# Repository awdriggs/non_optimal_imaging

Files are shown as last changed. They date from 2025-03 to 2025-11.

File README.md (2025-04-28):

This project explores how “non-optimal” digital cameras can be used to critically analyze photography. Each camera is missing one or more of the key affordances of a modern camera. By reintroducing limitations we can begin to understand our collective and individual relationships with photography at a moment when photography itself is being rapidly reshaped by machine learning.

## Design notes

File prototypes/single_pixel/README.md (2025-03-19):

# Single Pixel Camera
A "camera" that captures a single color value.

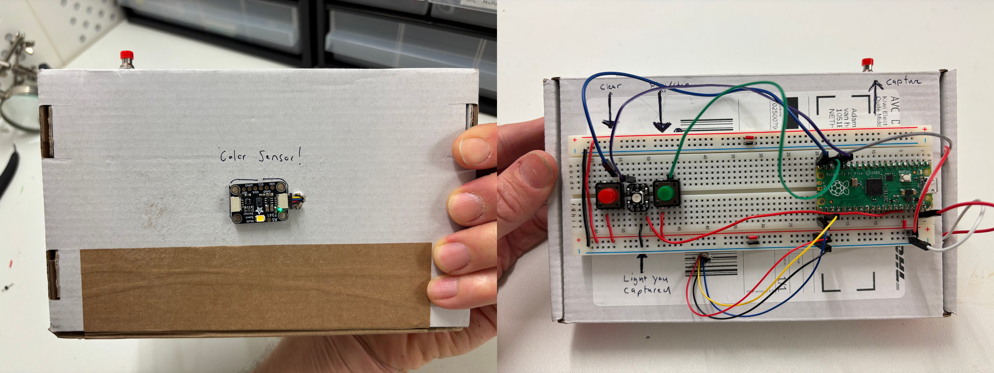
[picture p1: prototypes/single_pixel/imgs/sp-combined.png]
one pixel camera


The device uses a multispectral light sensor to capture visual light when a button is pressed. The multispectral data is converted to an RGB value and displayed on a single RGB led.
Buttons are used to review the captured colors and to clear the output.

Currently, there is no way to capture the colors from the device and they are deleted whenever the device is turned off.

## Components
- [Raspberry Pi Pico V1](https://www.raspberrypi.com/products/raspberry-pi-pico/)
- [Adafruit AS 7341 Multispectral Sensor](https://www.adafruit.com/product/4698)
- A Single [Neopixel](https://www.adafruit.com/product/1904)
- Three push buttons
- 3.3v LiPo battery
- [Adafruit Micro-Lipo Charger](https://www.adafruit.com/product/1904)

## Circuit
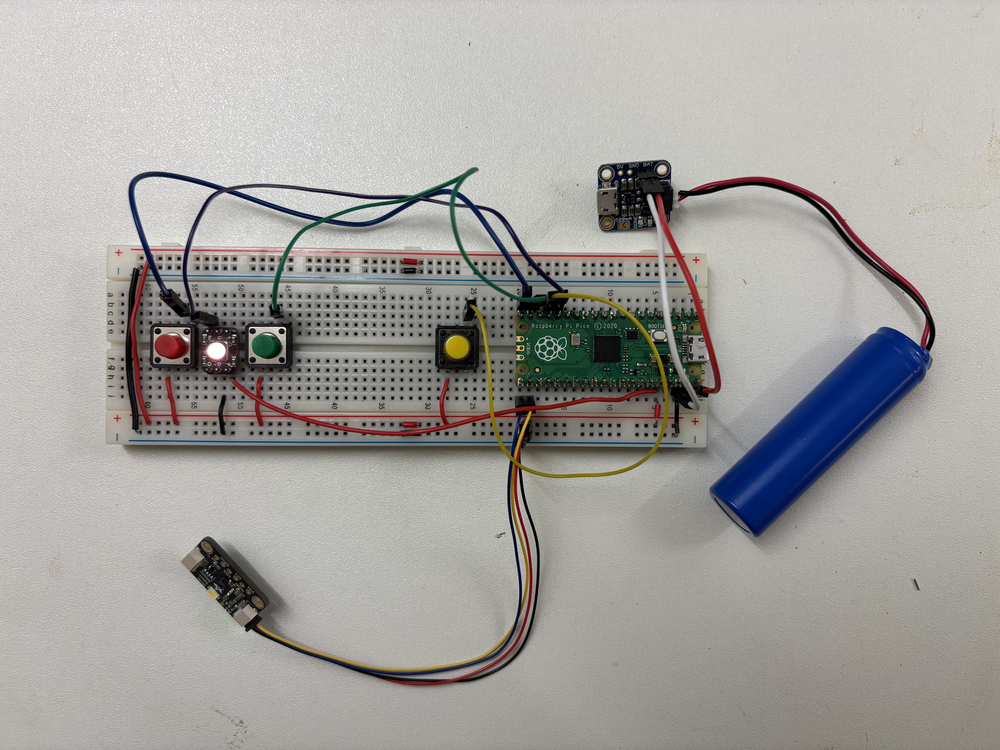
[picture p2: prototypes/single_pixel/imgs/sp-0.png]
breadboarded circuit


- Neopixel data to GP12
- Capture button to GP13
- Play button to GP14
- Clear button to GP15
- Sensor SCL to GP17
- Sensor SDA to GP16

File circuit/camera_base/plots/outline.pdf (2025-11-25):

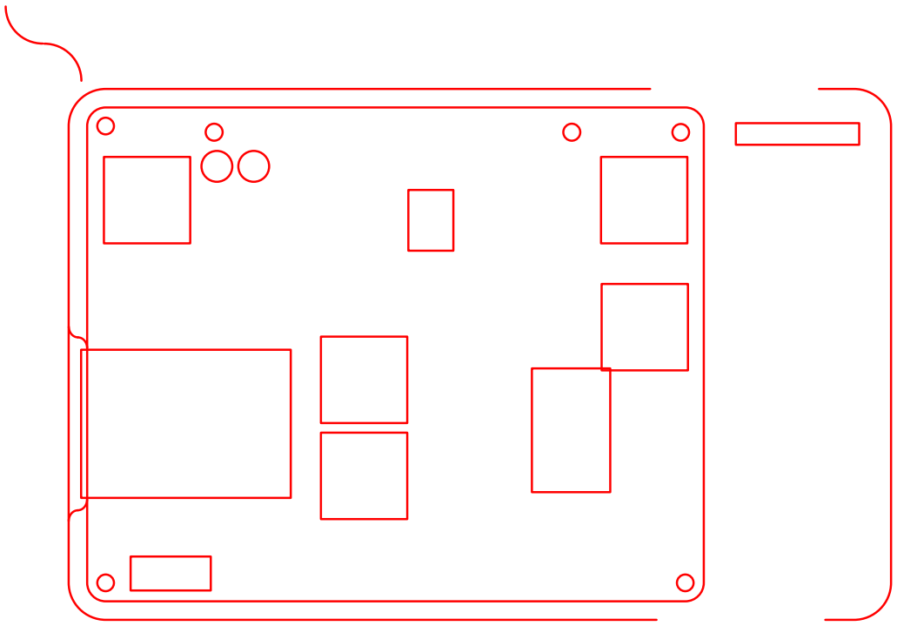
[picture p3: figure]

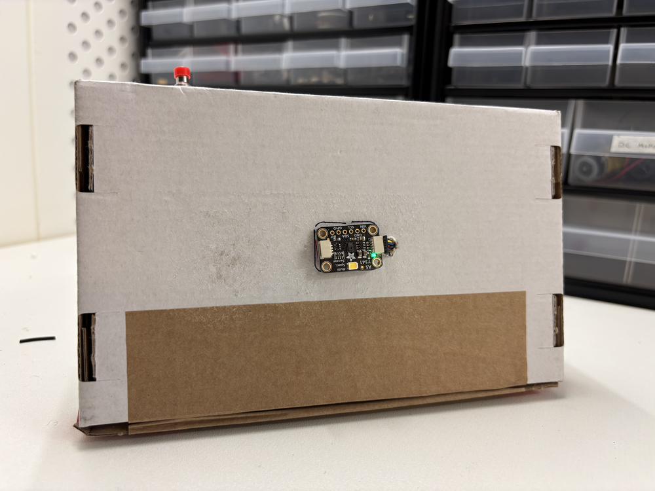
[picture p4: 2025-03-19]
prototypes/single_pixel/imgs/sp-8.png

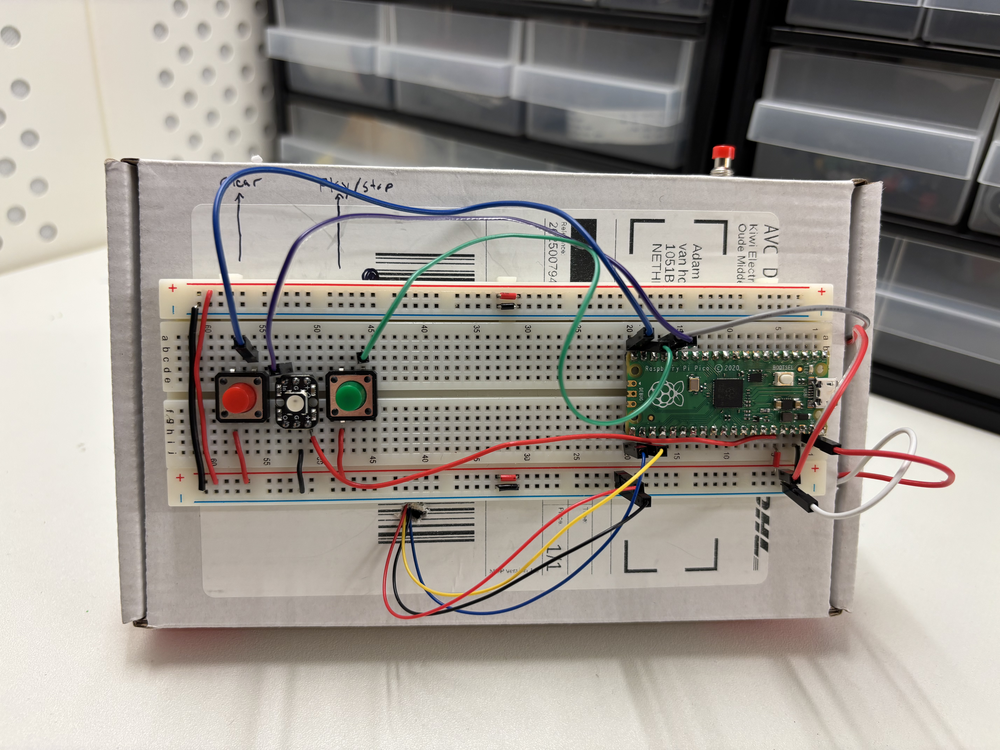
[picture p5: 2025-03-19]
prototypes/single_pixel/imgs/sp-9.png

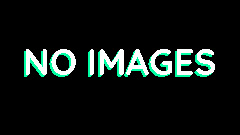
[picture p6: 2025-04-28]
camera/frontend/screens/no-images.jpg

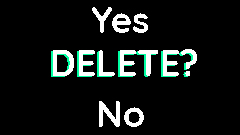
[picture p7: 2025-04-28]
camera/frontend/screens/delete.jpg

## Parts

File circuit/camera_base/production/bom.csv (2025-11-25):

Designator | Footprint | Quantity | Value | LCSC Part #
D1 | LED_D3.0mm | 1 | GPIO_19
D2 | LED_D3.0mm | 1 | LED
J1 | MODULE_RASPBERRY_PI_ZERO_2_W | 1 | Raspberry_Pi_4
J2 | PinHeader_2x03_P2.54mm_Vertical | 1 | Conn_02x03_Odd_Even
LIPO RIDER | SEED Studio LIPO Rider Plus | 1 | ~
R1, R2 | R_Axial_DIN0204_L3.6mm_D1.6mm_P5.08mm_Vertical | 2 | R
RV1 | Potentiometer_Alps_RK163_Single_Horizontal | 1 | R_Potentiometer_US
S4 | 5D_Button | 1 | ~
SCREEN | TFT 1.14 | 1 | ~
SW1, SW2, SW3, SW5 | PUSH_BUTTON_12mm | 4 | SW_Push_Dual
U1 | switch | 1 | ~

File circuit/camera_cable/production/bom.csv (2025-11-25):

Designator | Footprint | Quantity | Value | LCSC Part #
J1 | FPC_15pin_1mm_Vertical | 1 | ~
J2 | FPC_22pin_0.5mm_Vertical | 1 | ~

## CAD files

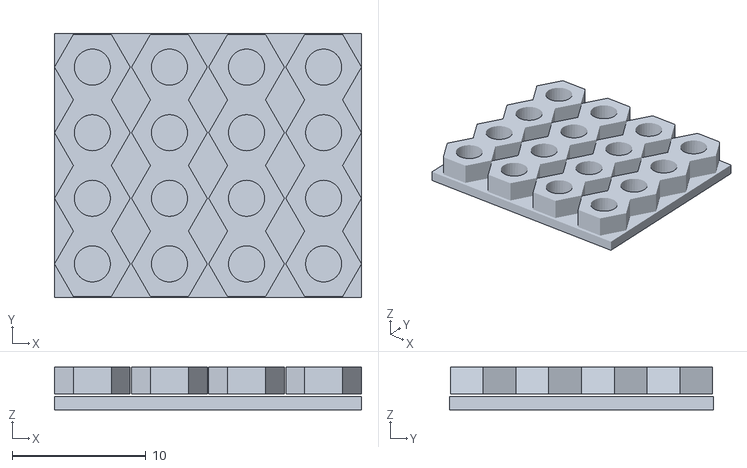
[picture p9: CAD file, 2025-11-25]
enclosure/spacer.stl
22.9 x 19.7 x 3.20

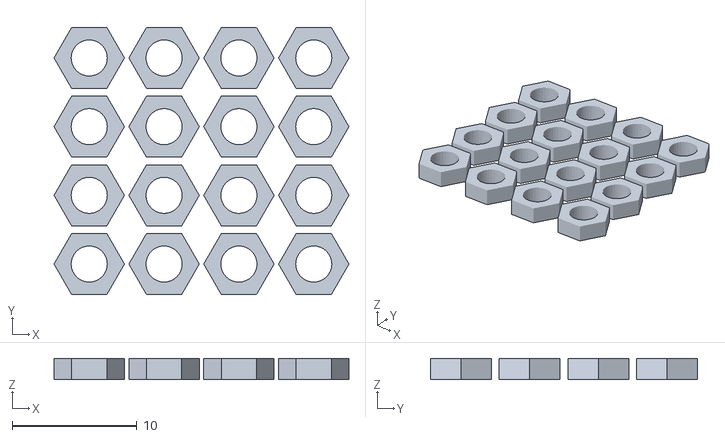
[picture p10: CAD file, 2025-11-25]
enclosure/spacers_no_base.stl
23.7 x 21.4 x 1.70

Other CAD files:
enclosure/no_enclosure_cut_ready.3dm

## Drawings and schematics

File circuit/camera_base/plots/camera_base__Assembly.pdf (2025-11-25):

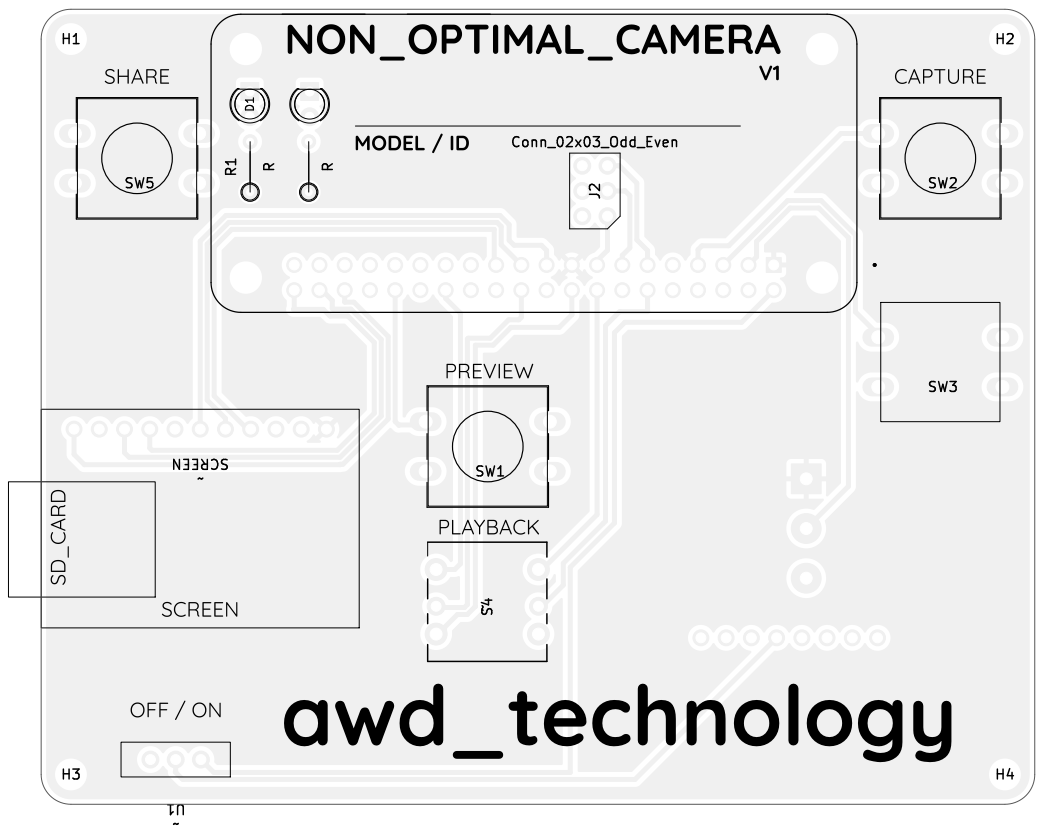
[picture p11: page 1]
D Date: KiCad; E.D.A. 9.0.1 Size: A4; Rev:; Id: /1 Title: File: camera_base.kicad_pcb Sheet: Black; And; White; TOP; Board2Pdf:; Black; TOP -; Page; ~S4 SW5 H1 H2 D1 H4 SW3 SW2 ~U1 SW1 Conn_02x03_Odd_Even J2 H3

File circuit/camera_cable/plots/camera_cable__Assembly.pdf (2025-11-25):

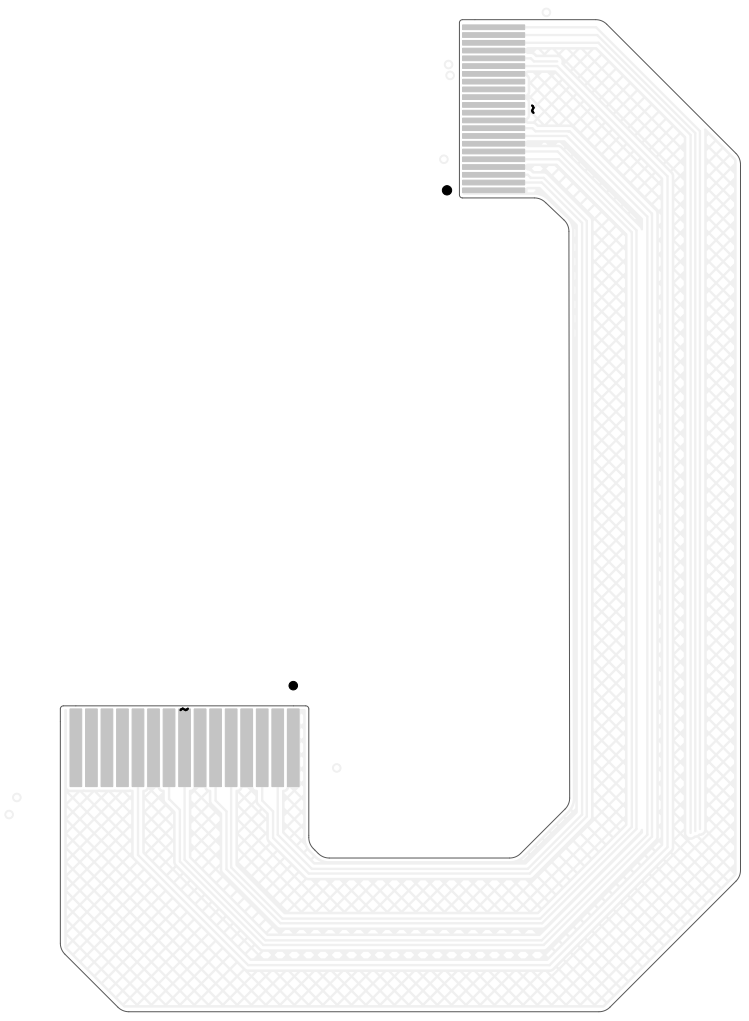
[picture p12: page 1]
D Date: KiCad; E.D.A. 9.0.1 Size: A4; Rev:; Id: /1 Title: File: camera_cable.kicad_pcb Sheet: Black; And; White; TOP; Board2Pdf:; Black; TOP -; Page

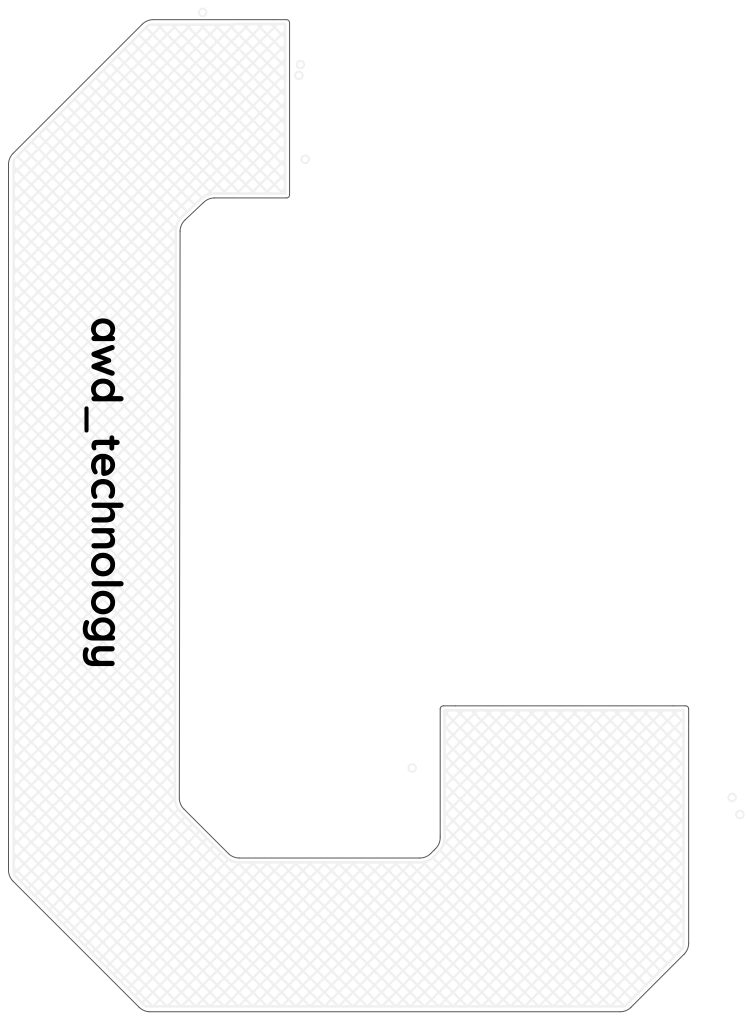
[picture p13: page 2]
D Date: KiCad; E.D.A. 9.0.1 Size: A4; Rev:; Id: /1 Title: File: camera_cable.kicad_pcb Sheet: Black; And; White; BOT Board2Pdf:; Black; BOT -; Page 2/2

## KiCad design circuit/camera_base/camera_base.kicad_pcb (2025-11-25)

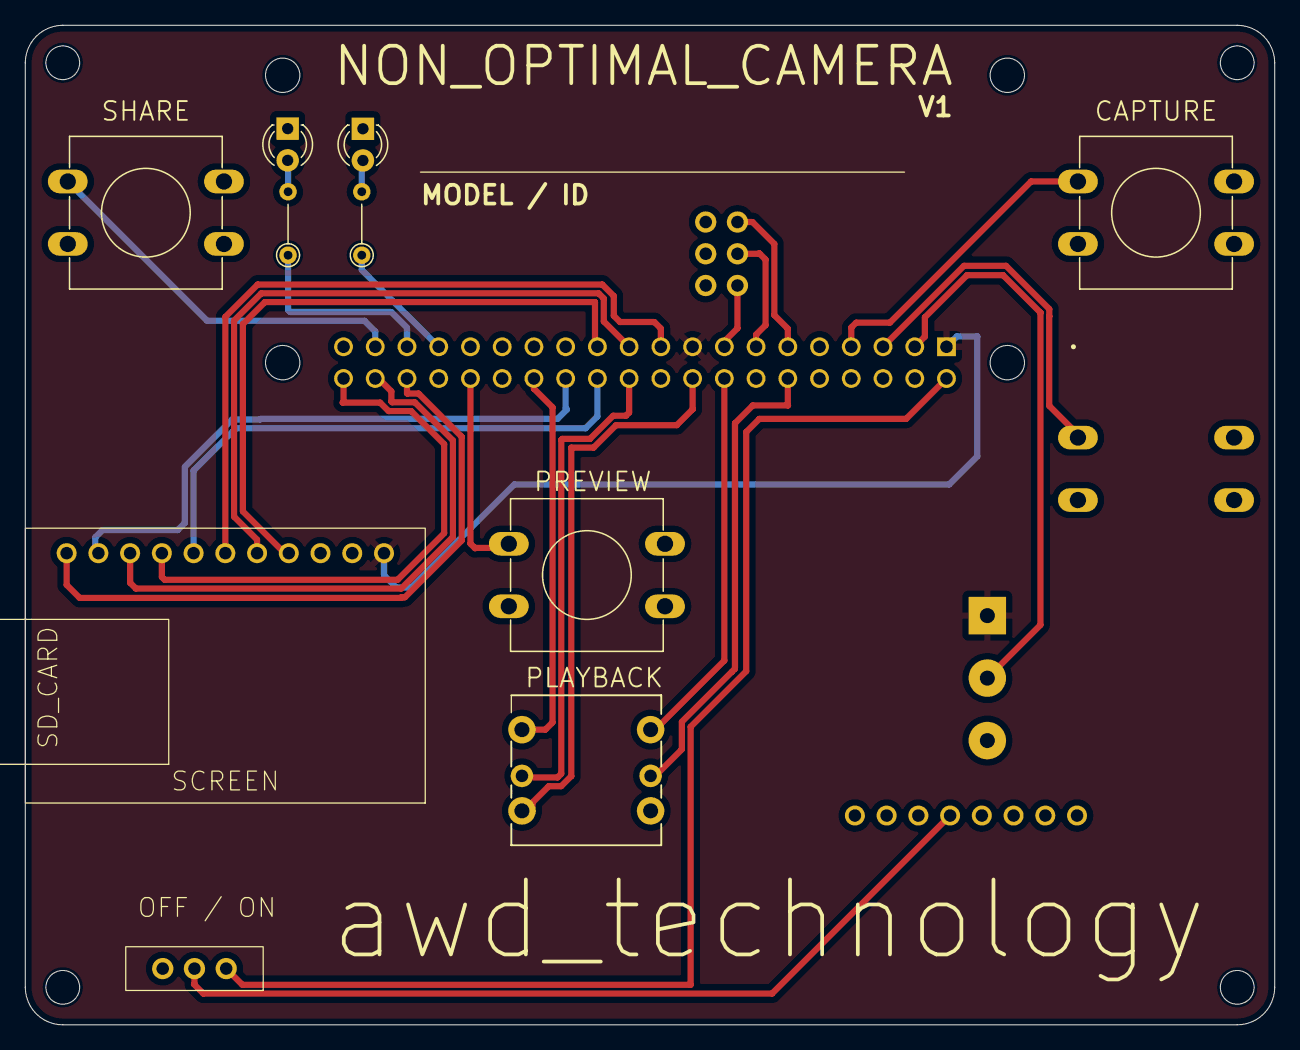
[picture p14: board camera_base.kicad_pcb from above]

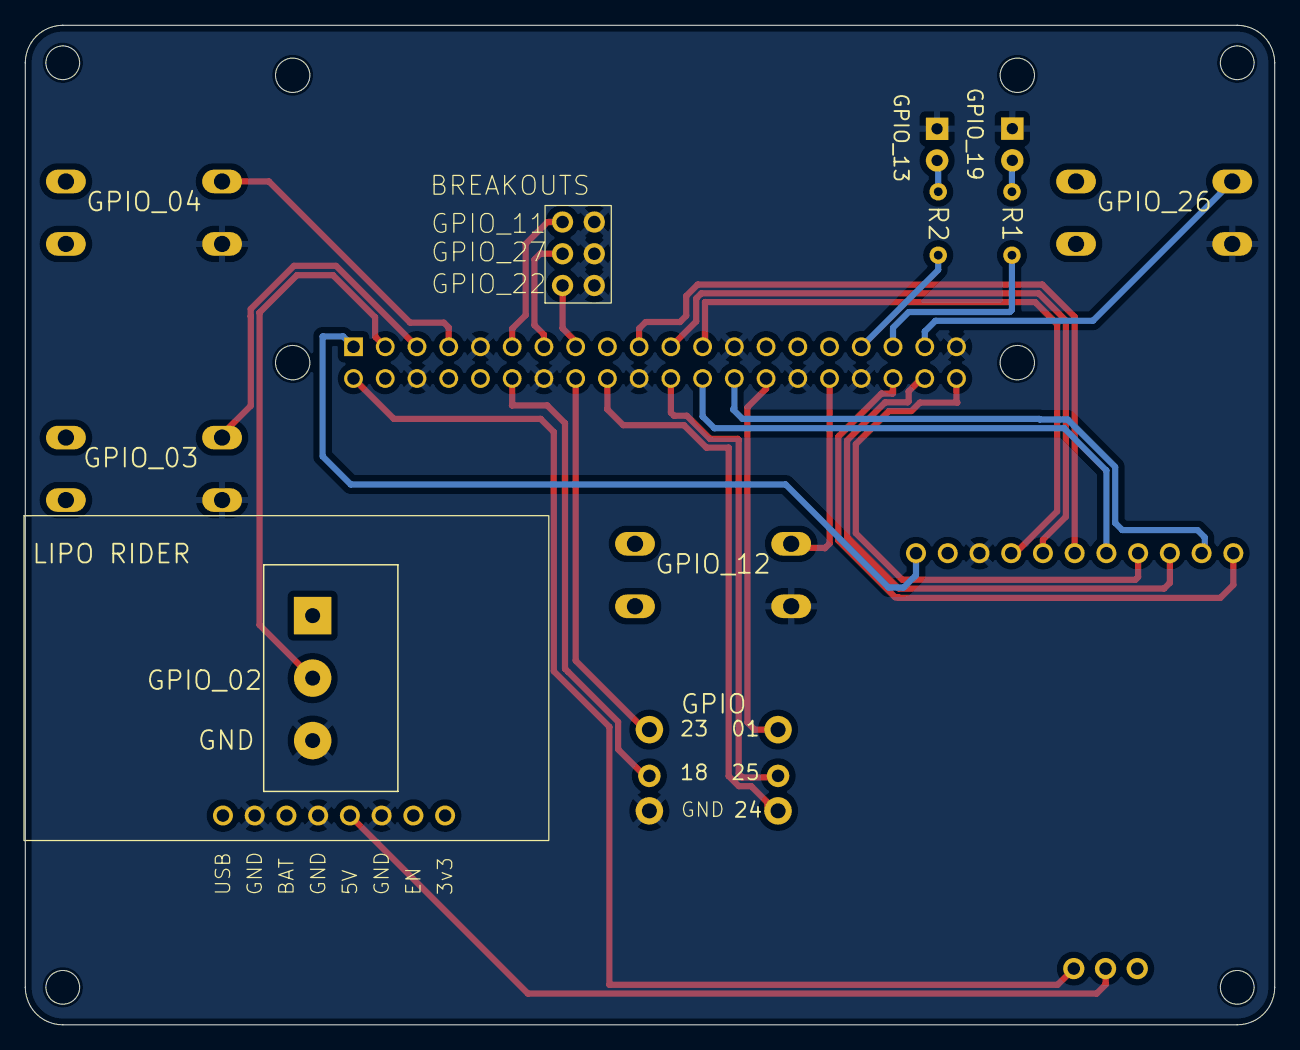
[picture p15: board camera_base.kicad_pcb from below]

Board: 2 copper layers, 100.0 x 80.0 mm, 19 parts (2 on the bottom side), 29 nets.

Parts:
D1: GPIO_19; LED_D3.0mm
D2: LED; LED_D3.0mm
H1, H2, H3, H4: MountingHole; MountingHole_2.7mm_M2.5
J1: Raspberry_Pi_4; MODULE_RASPBERRY_PI_ZERO_2_W
J2: Conn_02x03_Odd_Even; PinHeader_2x03_P2.54mm_Vertical
LIPO RIDER: SEED Studio LIPO Rider Plus
R1, R2: R; R_Axial_DIN0204_L3.6mm_D1.6mm_P5.08mm_Vertical
RV1: R_Potentiometer_US; Potentiometer_Alps_RK163_Single_Horizontal
S4: 5D_Button
SCREEN: TFT 1.14
SW1, SW2, SW3, SW5: SW_Push_Dual; PUSH_BUTTON_12mm
U1: switch

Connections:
3v3: J1.1 (3V3), J1.17 (3V3), RV1.1, SCREEN.1 (Vin)
CE0: J1.24 (~CE0_SPI0/GPIO08), SCREEN.7 (TFTCS)
CE1: J1.26 (~CE1_SPI0/GPIO07), SCREEN.10 (SDCS)
GND: D1.1 (K), D2.1 (K), J1.6 (GND), J1.9 (GND), J1.14 (GND), J1.20 (GND), J1.25 (GND), J1.30 (GND), J1.34 (GND), J1.39 (GND), J2.2, J2.4, J2.6, LIPO RIDER.3 (GND), LIPO RIDER.5 (GND), LIPO RIDER.7 (GND), RV1.3, S4.4 (COMMON), SCREEN.3 (GND), SW1.2, SW2.2, SW3.2, SW5.2
GPIO_01: J1.28 (ID_SC_I2C0/GPIO01), S4.1 (A)
GPIO_02: J1.3 (SDA_I2C1/GPIO02), RV1.2
GPIO_03: J1.5 (SCL_I2C1/GPIO03), SW3.1
GPIO_04: J1.7 (GPCLK0/GPIO04), SW2.1
GPIO_11: J1.11 (GPIO17/SPI1_~CE1), J2.5
GPIO_12: J1.32 (GPIO12/PWM0), SW1.1
GPIO_13: J1.33 (GPIO13/PWM1), R2.1
GPIO_16: J1.36 (GPIO16/SPI1_~CE2), SCREEN.11 (LIT)
GPIO_18: J1.12 (GPIO18/SPI1_~CE0/PCM_CLK/PWM0), S4.5 (D)
GPIO_19: J1.35 (GPIO19/SPI1_MISO/PCM_FS), R1.1
GPIO_20: J1.38 (GPIO20/SPI1_MOSI/PCM_DIN/PWM1), SCREEN.9 (DC)
GPIO_21: J1.40 (GPIO21/SPI1_SCLK/PCM_DOUT), SCREEN.8 (RST)
GPIO_22: J1.15 (GPIO22/SDIO_CLK), J2.1
GPIO_23: J1.16 (GPIO23/SDIO_CMD), S4.6 (CENTER)
GPIO_24: J1.18 (GPIO24/SDIO_DAT0), S4.3 (C)
GPIO_25: J1.22 (GPIO25/SDIO_DAT1), S4.2 (B)
GPIO_26: J1.37 (GPIO26/SDIO_DAT2), SW5.1
GPIO_27: J1.13 (GPIO27/SDIO_DAT3), J2.3
MISO: J1.21 (MISO_SPI0/GPIO09), SCREEN.5 (MISO)
MOSI: J1.19 (MOSI_SPI0/GPIO10), SCREEN.6 (MOSI)
unnamed: D1.2 (A), R1.2
unnamed: D2.2 (A), R2.2
unnamed: LIPO RIDER.4 (5V), U1.2 (Vnn)
unnamed: J1.2 (5V), U1.3 (NO)
SCLK: J1.23 (SCLK_SPI0/GPIO11), SCREEN.4 (SCK)

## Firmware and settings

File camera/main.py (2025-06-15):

import threading
import time
import digitalio
import board
from threading import Lock
from signal import pause
from pathlib import Path
from PIL import Image
from gpiozero import Button, LED
from camera import CameraController
from display import DisplayController
from share import start_server, stop_server
import pathlib
from capture import capture_image
from leds import status_led, share_led

# === Base Paths ===
BASE_DIR = pathlib.Path(__file__).resolve().parent
FRONTEND_DIR = BASE_DIR / "frontend"
CAPTURES_DIR = FRONTEND_DIR / "captures"
SCREENS_DIR = FRONTEND_DIR / "screens"

NO_IMAGES_FILE = SCREENS_DIR / "no-images.jpg"
DELETE_SCREEN_FILE = SCREENS_DIR / "delete.jpg"

# === Image Folder ===
image_dir = CAPTURES_DIR

# === Global State ===
camera_lock = Lock()
display_mode = "off"
previous_display_mode = "off"
playback_index = 0
image_list = []
camera_ready = threading.Event()
sharing_active = False
confirm_delete = False

# === Yellow LED Setup ===
status_led.blink(on_time=0.25, off_time=0.25)  # Start blinking immediately

# === Green LED Setup (Sharing Indicator) ===
share_led.off()  # Make sure it's OFF initially

# === Initialize components ===
camera = CameraController()
display = DisplayController()

# === Button Setup ===
capture_button = Button(4, bounce_time=0.1)
preview_button = Button(12, bounce_time=0.1)
playback_button = Button(23, bounce_time=0.1)
forward_button = Button(18, bounce_time=0.1)
back_button = Button(25, bounce_time=0.1)
share_button = Button(26, bounce_time=0.1)
up_button = Button(1, bounce_time=0.1)
down_button = Button(24, bounce_time=0.1)


# === Helper Functions ===
def get_images():
    global image_list, playback_index
    image_list = sorted([f.name for f in image_dir.iterdir() if f.is_file()])
    
    if image_list:
        playback_index = len(image_list) - 1
    else:
        playback_index = 0

    return image_list

def get_current_image():
    if not image_list:
        get_images()
    if image_list:
        return image_dir / image_list[playback_index]
    return None

def navigate_playback(direction):
    global playback_index

    if display_mode != "playback":
        set_display_mode("playback") 
        return

    if not image_list:
        get_images()
    if not image_list:
        return

    if direction == "forward":
        playback_index = (playback_index + 1) % len(image_list)
    elif direction == "back":
        playback_index = (playback_index - 1) % len(image_list)

    print(f"Playback {playback_index + 1}/{len(image_list)}")

# === Actions ===
# def capture_image():
#     with camera_lock:
#         print("Capturing...")
#         camera.capture_image()
#     get_images()

def set_display_mode(mode):
    global display_mode, previous_display_mode, confirm_delete
    if mode == "playback":
        previous_display_mode = display_mode

    if mode == display_mode:
        display_mode = "off"
    else:
        display_mode = mode

    #If leaving playback mode, clear any delete confirmation
    if display_mode != "playback":
        confirm_delete = False

    display.set_backlight(display_mode != "off")
    print(f"Display mode: {display_mode}")

def get_display_mode():
    return display_mode

def get_previous_display_mode():
    return previous_display_mode

def delete_current_image():
    global playback_index

    image_path = get_current_image()
    if image_path and image_path.exists():
        print(f"🗑 Deleting {image_path}")
        image_path.unlink()  # delete file

        # Capture current index before refreshing list
        old_index = playback_index

        get_images()  # refresh image list

        # Now carefully update playback_index:
        if len(image_list) == 0:
            playback_index = 0
        elif old_index >= len(image_list):
            playback_index = len(image_list) - 1
        else:
            playback_index = old_index

# === Button Handlers ===
def handle_share():
    global sharing_active

    if sharing_active:
        print("Stopping Share Server...")
        stop_server()
        share_led.off()
        sharing_active = False
    else:
        print("Starting Share Server...")
        threading.Thread(target=start_server, daemon=True).start()
        share_led.on()
        sharing_active = True

def handle_up():
    global confirm_delete

    if display_mode != "playback":
        set_display_mode("playback") 
        return

    # Don't allow delete if no real images
    if not image_list:
        return

    if not confirm_delete:
        # First press: show confirmation
        confirm_delete = True
        print("🟠 Delete confirmation ON")
    else:
        # Second press: delete image
        delete_current_image()
        confirm_delete = False

def handle_down():
    global confirm_delete

    if display_mode != "playback":
        set_display_mode("playback") 
        return

    if confirm_delete:
        # Cancel delete
        confirm_delete = False
        print("🟡 Delete cancelled")


def handle_capture():
    global display_mode, previous_display_mode

    if get_display_mode() == "playback":
        set_display_mode(get_previous_display_mode())
    else:
        return_to_display_off = False # track whether you changed the display mode

        # if in off mode, change to preivew, set flag to true 
        if display_mode == "off":
            set_display_mode("preview")
            return_to_display_off = True 
        
        #catpure image, this will show the image for three seconds 
        capture_image(camera, camera_lock, display)
        get_images()
          
        #if needed, switch back to the display being off 
        if return_to_display_off:
            set_display_mode("off")

capture_button.when_pressed = handle_capture
preview_button.when_pressed = lambda: set_display_mode("preview")
playback_button.when_pressed = lambda: set_display_mode("playback")
forward_button.when_pressed = lambda: navigate_playback("forward")
back_button.when_pressed = lambda: navigate_playback("back")
share_button.when_pressed = handle_share
up_button.when_pressed = handle_up
down_button.when_pressed = handle_down

# === Display Update Loop ===
def update_display_loop():
    while True:
        if display_mode == "preview":
            with camera_lock:
                frame = camera.get_frame()
            image = Image.fromarray(frame, 'RGB')
            display.show_image(image)

        elif display_mode == "playback":
            if confirm_delete:
                image = Image.open(DELETE_SCREEN_FILE)     
            else:
                image_path = get_current_image()
                if image_path:
                    image = Image.open(image_path)
                else:
                    image = Image.open(NO_IMAGES_FILE)     

            display.show_image(image)

            # saving this for now as an example of how to use the overlays. 
            # if confirm_delete:
            #     display.show_image(image, overlay_text="Delete? UP=Yes DOWN=No")
            # else:

        else:
            display.clear()

        time.sleep(0.03)

# === Start Everything ===
camera.start_preview()
status_led.off()

threading.Thread(target=update_display_loop, daemon=True).start()

print("Camera Ready")
set_display_mode("preview")
pause()

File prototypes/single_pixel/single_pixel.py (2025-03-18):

import time
import board
import digitalio

import busio  # Use busio for I2C communication
from adafruit_as7341 import AS7341

import neopixel

# Define I2C using specific pins for the Raspberry Pi Pico
# blue qt stemma cable goes to 16
# yellow qt stemma calbe goes to 17
i2c = busio.I2C(scl=board.GP17, sda=board.GP16)  # Replace with the correct pins

sensor = AS7341(i2c) #color sensor on a breakout board

class Button:
    def __init__(self, pin):
        self.button = digitalio.DigitalInOut(pin)
        self.button.switch_to_input(pull=digitalio.Pull.DOWN)
        self.previous_state = False  # Stores the last state
        self.on = False

    def is_pressed(self):
        """Returns True if button is currently pressed."""
        return self.button.value

    def is_released(self):
        """Returns True only when the button is released after being pressed."""
        current_state = self.button.value
        if not current_state and self.previous_state:
            self.previous_state = current_state
            self.on = not self.on #toggle on/off state
            return True
        self.previous_state = current_state
        return False

def bar_graph(read_value):
    scaled = int(read_value / 1000)
    return "[%5d] " % read_value + (scaled * "*")

def rgb():
    channels = get_channels() # a dict, ignoring the data you don't need

    # print(channels)
    # print(maxValue)
    normalized = normalize(channels)
    # print(normalized)

    r = 0.3 * normalized["F6"] + 0.5 * normalized["F7"] + 0.7 * normalized["F8"]
    g = 0.3 * normalized["F4"] + 0.7 * normalized["F5"]
    b = 0.5 * normalized["F2"] + 0.5 * normalized["F3"]

    # Normalize RGB values if any exceed 1.0
    max_rgb = max(r, g, b)
    if max_rgb > 1.0:
        r /= max_rgb
        g /= max_rgb
        b /= max_rgb

    # convert to a 0-255 scale:
    r_int = int(r * 255)
    g_int = int(g * 255)
    b_int = int(b * 255)

    return {"r": r_int, "g": g_int, "b": b_int}

def get_channels(): #package the channels as a dict
    data = {"F1": sensor.channel_415nm,
            "F2": sensor.channel_445nm,
            "F3": sensor.channel_480nm,
            "F4": sensor.channel_515nm,
            "F5": sensor.channel_555nm,
            "F6": sensor.channel_590nm,
            "F7": sensor.channel_630nm,
            "F8": sensor.channel_680nm
            }

    return data

def normalize(channels): #normalize according to the highest value
    max_val = max(channels.values()) # calc the max for normalizing
    return {key: value / max_val for key, value in channels.items()}

# Define buttons on different pins
capture = Button(board.GP13)
play = Button(board.GP14)
clear = Button(board.GP15)

colors = []

num_pixels = 1
pixel = board.GP12
on = False

pixels = neopixel.NeoPixel(pixel, num_pixels)
pixels.brightness = 0.2

while True:
    if capture.is_released():
        print("capture Released")
        color = rgb()
        colors.append(color)
        # print(colors)
        pixels.fill((color['r'], color['g'], color['b']))
        time.sleep(1);
        pixels.fill((0, 0, 0))

    if play.is_released():
        print("play Released")

    if clear.is_released():
        colors = [] #clear the colors
        print("clear  Released")

    # if(play.on):
    #     print("playing")
    #     for color in colors:
    #         pixels.fill((color['r'], color['g'], color['b']))
    #         time.sleep(0.2);

    while play.on:  # Only run the animation loop while play.on is True
        if len(colors) == 0:
            play.on = False
            break

        print("playing")
        for color in colors:
            pixels.fill((color['r'], color['g'], color['b']))
            time.sleep(0.2)

        # Check if the button is pressed again to stop the animation
            if play.is_released() :
                play.on = False  # Stop playing when button is pressed again
                pixels.fill((0, 0, 0))  # Turn off LEDs
                print("Stopped Playing")
                break  # Exit the for loop

            if clear.is_released():
                play.on = False
                pixels.fill((0, 0, 0))  # Turn off LEDs
                colors = [] #clear the colors
                break

    time.sleep(0.05)  # Small debounce delay

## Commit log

2025-03-28 button update
2025-04-03 image playback prototype
2025-04-16 tested on the board!
2025-04-28 base camera working
2025-04-28 base camera refactor done
2025-04-29 refactoring camera and capture
2025-05-04 tilt and shake prototyped
2025-06-15 threaded push
